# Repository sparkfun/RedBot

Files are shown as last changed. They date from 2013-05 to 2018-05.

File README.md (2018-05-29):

SparkFun RedBot
===============

<table class="table table-hover table-striped table-bordered">
  <tr align="center">
   <td><a href="https://www.sparkfun.com/products/12097">RedBot Mainboard</a></td>
   <td><a href="https://www.sparkfun.com/products/12649">RedBot Inventor's Kit for RedBot</a></td>
  </tr>
  <tr align="center">
    <td>RedBot Mainboard [<a href="https://www.sparkfun.com/products/12097">ROB-12097</a>]</td>
    <td>SparkFun Inventor's Kit for RedBot [<a href="https://www.sparkfun.com/products/12649">ROB-12649</a>]</td>
  </tr>
</table>

Design files and firmware files for the [RedBot Main board](https://www.sparkfun.com/products/11622).

Repository Contents
-------------------

* **/Documentation** - Documentation for the library's public API
* **/Hardware** - Eagle PCB layout files
* **/Libraries/Arduino/RedBot** - RedBot support library
* **/Production** - Files to support SparkFun production

Documentation
--------------

* **[Installing an Arduino Library Guide](https://learn.sparkfun.com/tutorials/installing-an-arduino-library)** - Basic information on how to install an Arduino library.
* **[Product Repository](https://github.com/sparkfun/RedBot)** - Main repository (including hardware files) for the RedBot.
* **[Library Repository](https://github.com/sparkfun/SparkFun_Redbot_Arduino_Library)** - Arduino library for the RedBot.
* **[Assembly Guide](https://learn.sparkfun.com/tutorials/assembly-guide-for-redbot-with-shadow-chassis)** - Basic hookup guide for the RedBot.
* **[Experiment Guide](https://learn.sparkfun.com/tutorials/experiment-guide-for-redbot-with-shadow-chassis)** - Experiment guide for the RedBot.

Product Versions
----------------
This repository only contains the hardware files for the RedBot Main board. There are several different support products available for the RedBot Kit however.

* [ROB-12097](https://www.sparkfun.com/products/12097) - RedBot Main Board.
* [ROB-12649](https://www.sparkfun.com/products/12649) - RedBot SparkFun Inventor's Kit
* *[ROB-13166 (RETIRED)](https://www.sparkfun.com/products/13166) - RedBot Basic Kit*
* [ROB-12567](https://www.sparkfun.com/products/12567) - RedBot Buzzer
* [SEN-11999](https://www.sparkfun.com/products/11999) - RedBot Mechanical Bumper
* [SEN-12589](https://www.sparkfun.com/products/12589) - RedBot Accelerometer
* [SEN-11769](https://www.sparkfun.com/products/11769) - RedBot Line Sensor
* [SEN-13582](https://www.sparkfun.com/products/13582) - SparkFun Line Follower Array

License Information
-------------------

This product is _**open source**_! 

Please review the LICENSE.md file for license information. 

If you have any questions or concerns on licensing, please contact techsupport@sparkfun.com.

Distributed as-is; no warranty is given.

- Your friends at SparkFun.

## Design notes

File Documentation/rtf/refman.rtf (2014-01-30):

begin body

TITLE

AUTHOR
Version
CREATEDATE

Table of Contents

Table of contents

Class Index
Class List
Here are the classes, structs, unions and interfaces with brief descriptions:
RedBotAccel pagenum
RedBotMotor pagenum
RedBotSensor pagenum

Class Documentation
RedBotAccel Class Reference
AAAAAAAAAAAAAAAAAAAA
#include <RedBot.h>

Public Member Functions
RedBotAccel ()
void read ()
void enableBump ()
boolean checkBump ()
void setBumpThresh (int xThresh)
Public Attributes
int x
int y
int z

Detailed Description
A class for controlling the RedBot's accelerometer.
Since the RedBot's accelerometer uses the I2C protocol, and is only connected to A4 and A5 on the RedBot, there should only ever be a single object of this class instantiated in your application/sketch.

Constructor & Destructor Documentation
RedBotAccel::RedBotAccel ()
AAAAAAAAABAAAAAAAAABCreates an object of the class RedBotAccel

Member Function Documentation
boolean RedBotAccel::checkBump ()
AAAAAAAAACAAAAAAAAACCheck to see if a "bump" event has occurred.
This method returns true if a "bump" event has occurred since the last time that RedBotAccel::checkBump() has been called. Before using RedBotAccel::checkBump(), bump detection must be enabled via RedBotAccel::enableBump(). Note that a "bump" is an acceleration event that occurs along the X-axis.
void RedBotAccel::enableBump ()
AAAAAAAAADAAAAAAAAADEnable bump detection.
A "bump" is an acceleration event that occurs along the X-axis. After enabling bump detection, use to RedBotAccel::checkBump() to do the actual detection.
void RedBotAccel::read ()
AAAAAAAAAEAAAAAAAAAECopy the current accelerometer values into the class's attributes.
In order to "read" the accelerometer's current state, you must first call RedBotAccel::read() to set RedBotAccel::x, RedBotAccel::y, and RedBotAccel::z which you can then read and do your own processing.
void RedBotAccel::setBumpThresh (int xThresh)
AAAAAAAAAFAAAAAAAAAFSet the threshold for what is considered a "bump" event.
If the default "bump" event threshold is too strong or too weak for your application/sketch, you can provide a value of 0-127 inclusive to use as the new threshold. Prior to calling RedBotAccel::setBumpThresh(int xTresh) "bump" detection must first be enabled via RedBotAccel::enableBump().

Member Data Documentation
int RedBotAccel::x
AAAAAAAAAGAAAAAAAAAGRead the last copied X-axis reading.
This class member is set by calling RedBotAccel::read() and can be used to do your own data processing.
int RedBotAccel::y
AAAAAAAAAHAAAAAAAAAHRead the last copied Y-axis reading.
This class member is set by calling RedBotAccel::read() and can be used to do your own data processing.
int RedBotAccel::z
AAAAAAAAAIAAAAAAAAAIRead the last copied Z-axis reading.
This class member is set by calling RedBotAccel::read() and can be used to do your own data processing.

The documentation for this class was generated from the following files:
Arduino/RedBot/RedBot.h
Arduino/RedBot/RedBotAccel.cpp

RedBotMotor Class Reference
AAAAAAAAAJAAAAAAAAAJ
#include <RedBot.h>

Public Member Functions
RedBotMotor ()
void drive (int speed)
void leftDrive (int speed)
void rightDrive (int speed)
void pivot (int speed)
void stop ()
void leftStop ()
void rightStop ()
void brake ()
void leftBrake ()
void rightBrake ()

Detailed Description
A class for controlling the RedBot's motors. A single object of the RedBotMotor class controls both the left and right motors of the RedBot.

Constructor & Destructor Documentation
RedBotMotor::RedBotMotor ()
AAAAAAAAAKAAAAAAAAAKCreate a new object of the RedBotMotor class.
A single RedBotMotor instance is used for both motors on the RedBot.

Member Function Documentation
void RedBotMotor::brake ()
AAAAAAAAALAAAAAAAAALImmediately stop both motors and hold their current positions.
The RedBotMotor::brake() method effectively shorts the terminals of the motors and therefore results in the motors stopping much more quickly than the RedBotMotor::stop() method. After a call to RedBotMotor::brake(), the motors will be much harder to turn, which will allow the RedBot to hold its position on a slope.
Usage Example:
#include <RedBot.h>

RedBotMotor motor;
void setup() {
}
void loop() {
// Drive for a bit
for (int x = 0; x < 1000; x++) {
motor.drive (200);
}
// Stop the motors and hold current position
motor.brake();
}
void RedBotMotor::drive (int speed)
AAAAAAAAAMAAAAAAAAAMRun both motors at a given speed.
If speed is a positive integer, drives both motors forward, and if speed is a negative integer, drives both motors backward. In either case, the motors are driven at the absolute value at speed . Allowable values for speed are -255 to 255 inclusive, however values in -75 to 0 and 0 to 75 inclusive may not provide enough torque to start the motor turning.
Usage Example:
#include <RedBot.h>

RedBotMotor motor;
void setup() {
}
void loop () {
// Drive forward at a speed of 200
motor.drive (200);
// Drive backward at a speed of 150
motor.drive (-150)
}
void RedBotMotor::leftBrake ()
AAAAAAAAANAAAAAAAAANImmediately stop the left motor and hold its current position.
The RedBotMotor::leftBrake() method effectively shorts the terminals of * the left motor and therefore results in the motor stopping much more quickly than the RedBotMotor::leftRtop() method. After a call to RedBotMotor::leftBrake(), the motor will be much harder to turn, which will allow the RedBot to hold its position on a slope. The right motor will still be able to be driven via RedBotMotor::rightDrive() method.
void RedBotMotor::leftDrive (int speed)
AAAAAAAAAOAAAAAAAAAORun the left motor at a given speed.
If speed is a positive integer, drives the motor forward, and if speed is a negative integer, drives motor backward. In either case, the motor is driven at the absolute value at speed . Allowable values for speed are -255 to 255 inclusive, however values in -75 to 0 and 0 to 75 inclusive may not provide enough torque to start the motor turning.
Usage Example:
#include <RedBot.h>

RedBotMotor motor;
void setup() {
}
void loop () {
// Drive the left motor forward at a speed of 200
motor.LeftDrive (200);
// Drive the left motor backward at a speed of 150
motor.leftDrive (-150)
}
void RedBotMotor::leftStop ()
AAAAAAAAAPAAAAAAAAAPDiscontinue PWM output to the left motor.
This method turns off the left motor by stopping PWM output to the motor. After a call to this method, the left motor will continue to coast for a short time. In order to continue driving just the right motor, use RedBotMotor::rightDrive(int speed)
void RedBotMotor::pivot (int speed)
AAAAAAAAAQAAAAAAAAAQPivot the RedBot to either the left or right.
If speed is a positive integer, the RedBot pivots to the left. If speed is a negative integer, the RedBot pivots to the right. In either case, the motors are driven in their respective directions at the absolute value of speed . When pivoting left, the left motor drives backwards and the right motor drives forward; when pivoting right, the motors drive in the opposite directions. Allowable values for speed are -255 to 255 inclusive, however values in -75 to 0 and 0 to 75 inclusive may not provide enough torque to start the motor turning.
Usage Example:
#include <RedBot.h>

RedBotMotor motor;
void setup() {
}
void loop() {
// Pivot to the left at a speed of 150
motor.pivot (150);
// Pivot to the right at a speed of 75
motor.pivot (-75);
}
void RedBotMotor::rightBrake ()
AAAAAAAAARAAAAAAAAARImmediately stop the right motor and hold its current position.
The RedBotMotor::rightBrake() method effectively shorts the terminals of the right motor and therefore results in the motor stopping much more quickly than the RedBotMotor::rightRtop() method. After a call to RedBotMotor::rightBrake(), the motor will be much harder to turn, which will allow the RedBot to hold its position on a slope. The left motor will still be able to be driven via RedBotMotor::leftDrive() method.
void RedBotMotor::rightDrive (int speed)
AAAAAAAAASAAAAAAAAASRun the right motor at a given speed.
If speed is a positive integer, drives the motor forward, and if speed is a negative integer, drives motor backward. In either case, the motor is driven at the absolute value at speed . Allowable values for speed are -255 to 255 inclusive, however values in -75 to 0 and 0 to 75 inclusive may not provide enough torque to start the motor turning.
Usage Example:
#include <RedBot.h>

RedBotMotor motor;
void setup() {
}
void loop () {
// Drive the right motor forward at a speed of 200
motor.RightDrive (200);
// Drive the right motor backward at a speed of 150
motor.rightDrive (-150)
}
void RedBotMotor::rightStop ()
AAAAAAAAATAAAAAAAAATDiscontinue PWM output to the right motor.
This method turns off the right motor by stopping PWM output to the motor. After a call to this method, the right motor will continue to coast for a short time. In order to continue driving just the left motor, use RedBotMotor::leftDrive(int speed)
void RedBotMotor::stop ()
AAAAAAAAAUAAAAAAAAAUDiscontinue PWM output to both motors.
This method turns off both motors by stopping PWM output to the motors. After a call to this method, the motors will continue to coast for a short time.
Usage Example:
#include <RedBot.h>

RedBotMotor motor;
void setup() {
}
void loop() {
// Drive for a bit
for (int x = 0; x < 1000; x++) {
motor.drive (200);
}
// Stop the motors
motor.stop();
}

The documentation for this class was generated from the following files:
Arduino/RedBot/RedBot.h
Arduino/RedBot/RedBotMotor.cpp

RedBotSensor Class Reference
AAAAAAAAAVAAAAAAAAAV
#include <RedBot.h>

Public Member Functions
RedBotSensor (int pin)
int read ()
boolean check ()
int setBGLevel ()
int setDetectLevel ()

Detailed Description
A class for controlling the RedBot's sensors.
A single object of the class RedBotSensor is needed for each sensor that you want to use on the RedBot.

Constructor & Destructor Documentation
RedBotSensor::RedBotSensor (int pin)
AAAAAAAAAWAAAAAAAAAWCreate a new object of the RedBotSensor class.
pin is the analog input pin that the sensor is connected to.
Usage Example:
#include <RedBot.h>

RedBotSensor sensor = RedBotSensor (A2);

Member Function Documentation
boolean RedBotSensor::check ()
AAAAAAAAAXAAAAAAAAAXDetermines if the current sensor reading is within the configured levels.
This method returns true if the sensor's current analog value is within the configured levels. If the sensor's current analog value is outside the configured levels, RedBotSensor::check() returns false .
int RedBotSensor::read ()
AAAAAAAAAYAAAAAAAAAYRead the analog level of the sensor.
This method is primarily used when you want to do your own data processing instead of relying on the library's edge detection.
int RedBotSensor::setBGLevel ()
AAAAAAAAAZAAAAAAAAAZSet the background/default sensor reading level.
Calling this method sets the sensor's reading level that corresponds to an uninteresting sensor reading. For example, if you are trying to follow a black line on a white background, you would call RedBotSensor::setBPLevel() when the light sensor is over the white background.
int RedBotSensor::setDetectLevel ()
AAAAAAAABAAAAAAAAABASet the forground/active sensor reading level.
Calling this method sets the sensor's reading level that corresponds to an interesting sensor reading. For example, if you are trying to follow a black line on a white background, you would call RedBotSensor::setDetectLevel() when the light sensor is over the black background.

The documentation for this class was generated from the following files:
Arduino/RedBot/RedBot.h
Arduino/RedBot/RedBotSensor.cpp

Index
INDEX

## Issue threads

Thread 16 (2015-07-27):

FTDI drivers and Codebender plugin not working to run from Browser

julesmoretti, 2015-07-27:
Hello there:

I have finished building the kit and am now at the following stage:
https://learn.sparkfun.com/tutorials/assembly-guide-for-redbot-with-shadow-chassis/10-run-it

I have a MacBook Pro retina and believe to have installed both the FTDI drivers and Codebender plugin.

At the very least the Codebender as it is listed in my chrome extensions as active.

The issue that I am facing is that within the "Test Some Code" section, I am unable to detect any other ports but:

```
/dev/cu.Bluetooth-Incoming-Port
/dev/cu.Bluetooth-Modem
```
So how can I troubleshoot this in order for me to be able to select COM42 as instructed in the tutorial?

Thank you for your help.

Jules

ToniCorinne, 2015-07-27:
Make sure you are powering the RedBot. If there's no power to the board, it won't show up in your available ports.

Double check you've completed these steps. If you aren't sure on these, reread the assembly guide and check out the images for additional help:
1) To program the RedBot from your browser, make sure you have the FTDI drivers and Codebender plugin) installed. Plug in the RedBot using a USB mini cable.
2) Turn the RedBot POWER switch to ON and the MOTOR switch to RUN.

ToniCorinne, 2015-07-27:
Also, your COM port will not necessarily be COM42. That number is assigned based on how many serial devices have been plugged in before. Check out our [terminal basics tutorial](https://learn.sparkfun.com/tutorials/terminal-basics/connecting-to-your-device) if you need additional help with this.

sean808080, 2015-11-13:
I'm having a similar problem in that the usbmodem port shows up.  The Arduino IDE works with it just fine.  The port when selected in the codebender test screen results in an error when attempting to load a test sketch:

Could not connect to your device. Make sure that you have connected it properly, that you have selected the correct settings (device type and port) and try again. More Info

Oh well....

tzikis, 2015-11-14:
hey @sean808080, can you please contact codebender's support at feedback.codebender.cc, in order to try and understand what's happening?

ToniCorinne, 2016-03-07:
We have updated this library and pushed the changes to both Codebender and the Arduino library manager. Please reopen this if you are still having issues.

Closed 2016-03-07.

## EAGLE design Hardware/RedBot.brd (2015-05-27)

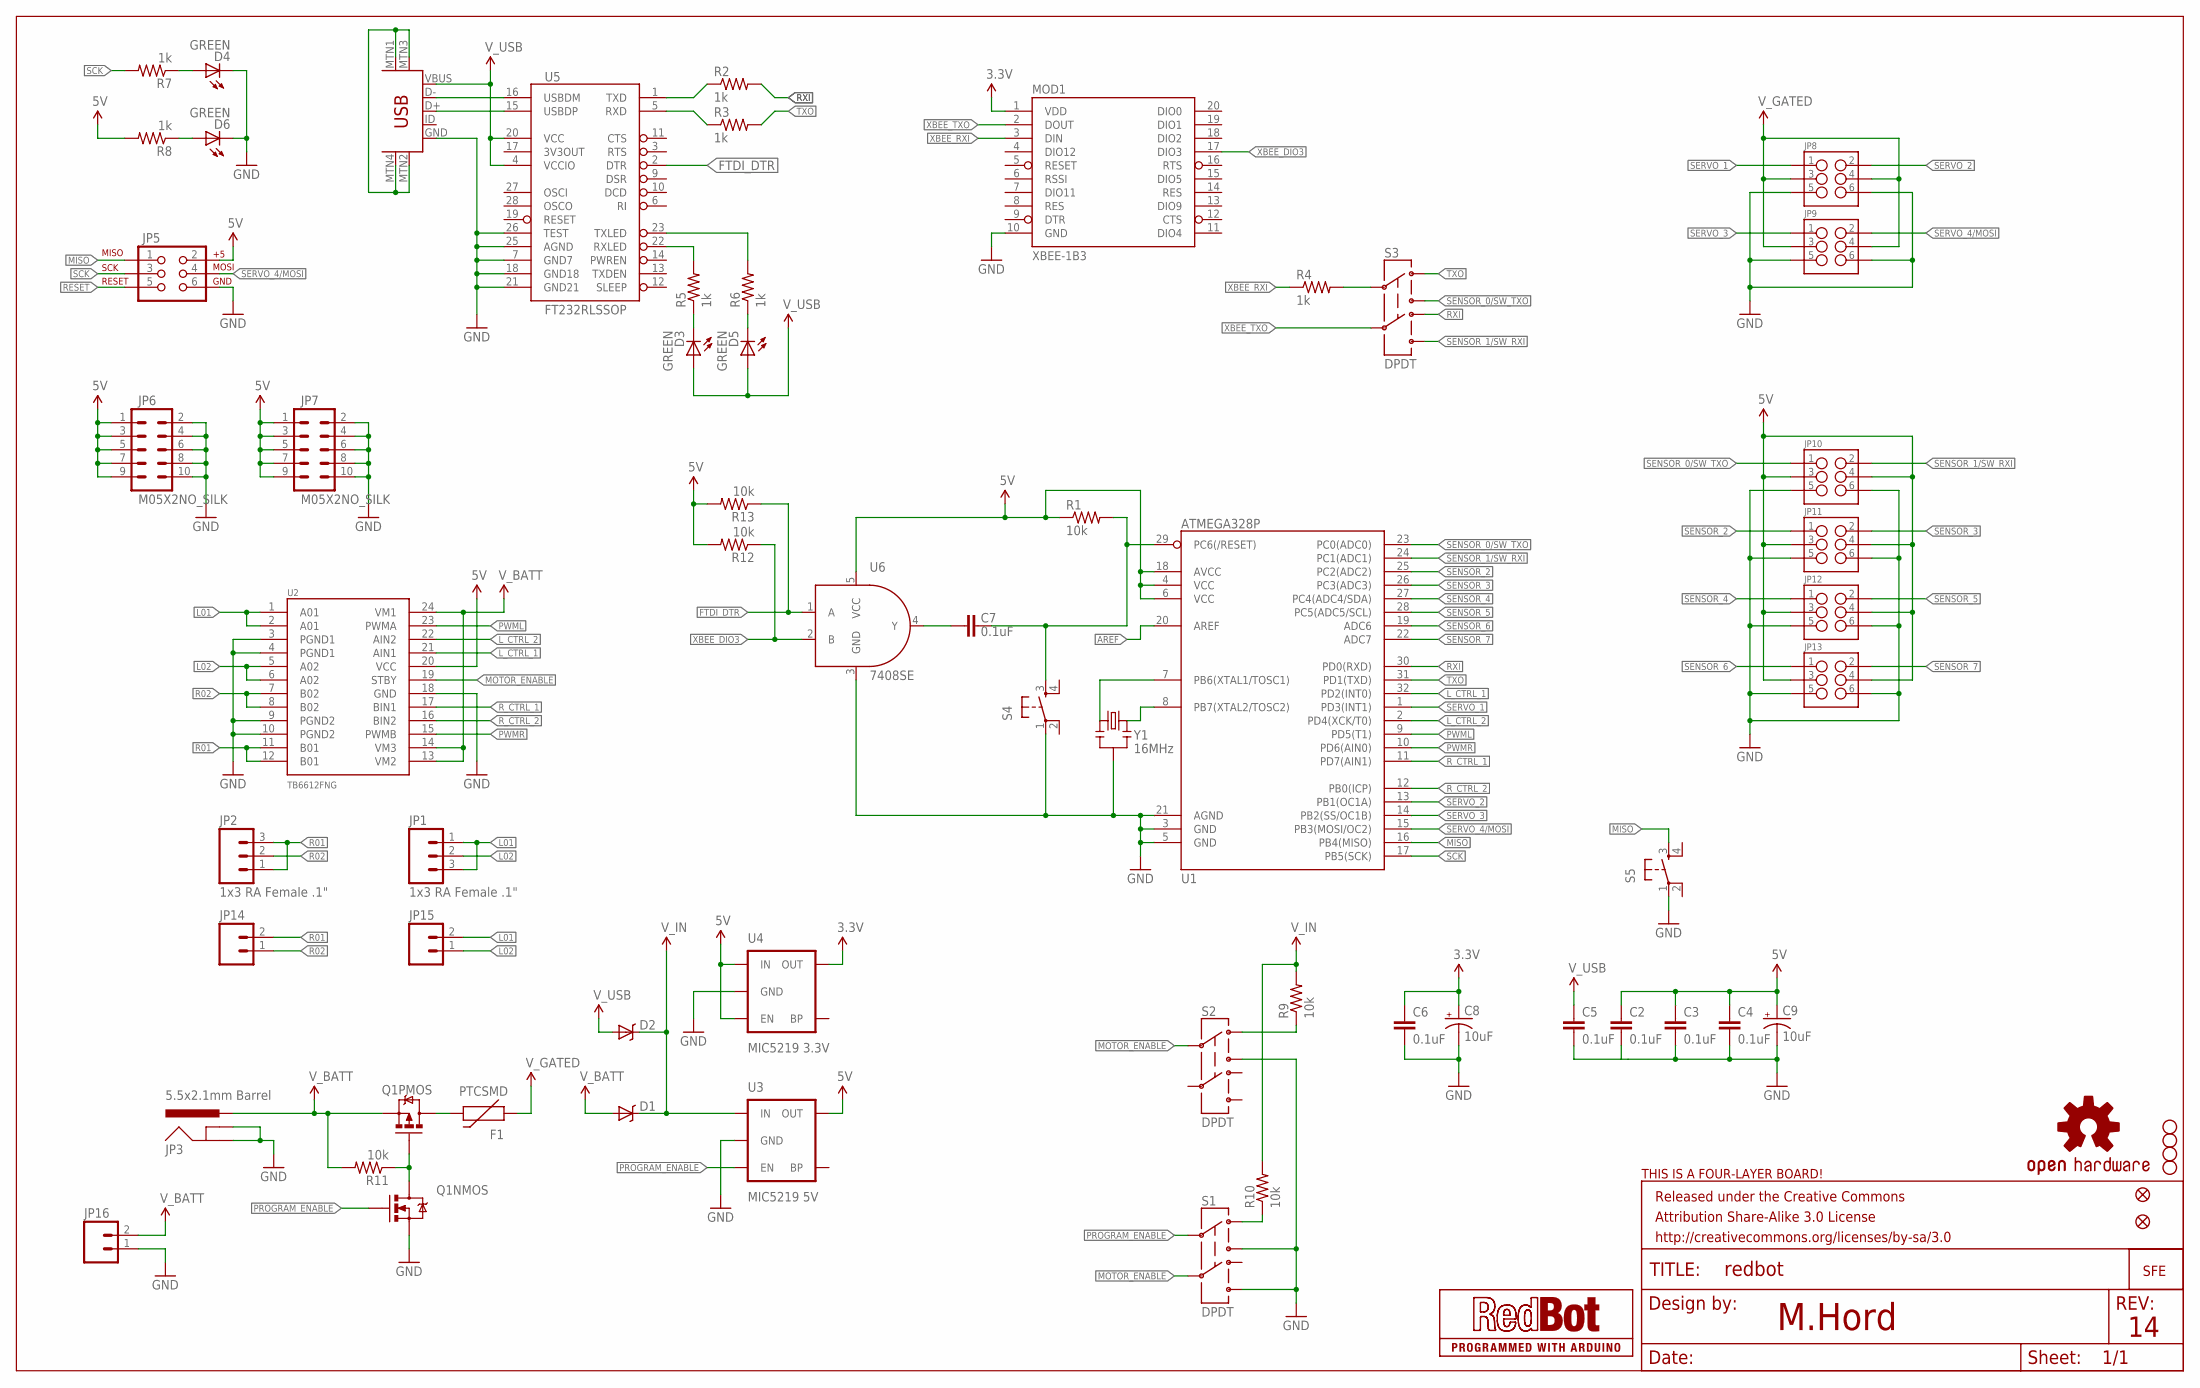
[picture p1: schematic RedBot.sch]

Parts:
C2, C3, C4, C5, C6, C7: 0.1uF; 0603-CAP
C8, C9: 10uF; EIA3216
D1, D2: B340A; SMA-DIODE
D3, D4, D5, D6: GREEN; LED-0603
F1: PTCSMD; PTC-1206
FID1, FID2: FIDUCIALUFIDUCIAL; MICRO-FIDUCIAL
FRAME1: FRAME-LETTER; CREATIVE_COMMONS
JP1, JP2: 1x3 RA Female .1"; 1X03_SMD_RA_FEMALE
JP3: 5.5x2.1mm Barrel; POWER_JACK_SMD
JP4: USB-B; USB-MINIB
JP5: AVR_SPI_PRG_6PTH; 2X3
JP6, JP7: M05X2NO_SILK; 2X5_NOSILK
JP8, JP9, JP10, JP11, JP12, JP13: M03X2SMT; 2X3_SMT_POSTS
JP14, JP15, JP16: M02PTH; 1X02
MOD1: XBEE-1B3; XBEE-SMD
Q1: IRF7509; MSOP8
R1, R9, R10, R11, R12, R13: 10k; 0603-RES
R2, R3, R4, R5, R6, R7, R8: 1k; 0603-RES
S1, S2, S3: DPDT; AYZ0202
S4, S5: TAC_SWITCHSMD; TACTILE_SWITCH_SMD
SFE-LOGO1: LOGO-SFENEW; SFE-NEW-WEBLOGO
STANDOFF1, STANDOFF2, STANDOFF3, STANDOFF4: STAND-OFF
U1: ATMEGA328P; TQFP32-08
U2: TB6612FNG; SSOP24
U3: MIC5219 5V; SOT23-5
U4: MIC5219 3.3V; SOT23-5
U5: FT232RLSSOP; SSOP28DB
U6: 7408SE; SOT353
U$17: OSHW-LOGOS; OSHW-LOGO-S
U$21: FOUR_LAYER_WARNING
U$23: REDBOT_LOGO
Y1: 16MHz; RESONATOR-SMD

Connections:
3.3V: C6.1, C8.A (+), MOD1.1 (VDD), U4.5 (OUT)
5V: C2.1, C3.1, C4.1, C9.A (+), JP5.2, JP6.1, JP6.3, JP6.5, JP6.7, JP6.9, JP7.1, JP7.3, JP7.5, JP7.7, JP7.9, JP10.3, JP10.4, JP11.3, JP11.4, JP12.3, JP12.4, JP13.3, JP13.4, R1.1, R8.2, R12.2, R13.2, U1.4 (VCC), U1.6 (VCC), U1.18 (AVCC), U2.20 (VCC), U3.5 (OUT), U4.1 (IN), U4.3 (EN), U6.5 (VCC)
AREF: U1.20 (AREF)
FT232_RXI: R3.1, U5.5 (RXD)
FT232_TXO: R2.1, U5.1 (TXD)
FTDI_DTR: R13.1, U5.2 (DTR), U6.1 (A)
GND: C2.2, C3.2, C4.2, C5.2, C6.2, C8.C (-), C9.C (-), D4.C, D6.C, JP3.GND (GNDBREAK), JP3.P$4 (GND), JP4.GND, JP5.6, JP6.2, JP6.4, JP6.6, JP6.8, JP6.10, JP7.2, JP7.4, JP7.6, JP7.8, JP7.10, JP8.5, JP8.6, JP9.5, JP9.6, JP10.5, JP10.6, JP11.5, JP11.6, JP12.5, JP12.6, JP13.5, JP13.6, JP16.1, MOD1.10 (GND), Q1.1 (S), S1.3, S1.6, S2.3, S4.1, S5.1, U1.3 (GND), U1.5 (GND), U1.21 (AGND), U2.3 (PGND1), U2.4 (PGND1), U2.9 (PGND2), U2.10 (PGND2), U2.18 (GND), U3.2 (GND), U4.2 (GND), U5.7 (GND7), U5.18 (GND18), U5.21 (GND21), U5.25 (AGND), U5.26 (TEST), U6.3 (GND), Y1.2
L01: JP1.1, JP1.3, JP15.2, U2.1 (A01), U2.2 (A01)
L02: JP1.2, JP15.1, U2.5 (A02), U2.6 (A02)
L_CTRL_1: U1.32 (PD2(INT0)), U2.21 (AIN1)
L_CTRL_2: U1.2 (PD4(XCK/T0)), U2.22 (AIN2)
MISO: JP5.1, S5.3, U1.16 (PB4(MISO))
MOTOR_ENABLE: S1.5, S2.2, U2.19 (STBY)
unnamed: R4.2, S3.2
unnamed: Q1.4 (G), Q1.7 (D), Q1.8 (D), R11.1
unnamed: D5.C, R6.1
unnamed: D3.C, R5.1
unnamed: C7.2, U6.4 (Y)
unnamed: JP4.MTN1 (MTN2), JP4.MTN2 (MTN3), JP4.MTN3 (MTN1), JP4.MTN4
unnamed: D4.A, R7.1
unnamed: D6.A, R8.1
unnamed: F1.2, Q1.5 (D), Q1.6 (D)
unnamed: R9.1, S2.1
unnamed: U1.8 (PB7(XTAL2/TOSC2)), Y1.3
unnamed: U1.7 (PB6(XTAL1/TOSC1)), Y1.1
unnamed: JP4.D-, U5.16 (USBDM)
unnamed: JP4.D+, U5.15 (USBDP)
PG_EN: R10.1, S1.1
PROGRAM_ENABLE: Q1.2 (G), S1.2, U3.3 (EN)
PWML: U1.9 (PD5(T1)), U2.23 (PWMA)
PWMR: U1.10 (PD6(AIN0)), U2.15 (PWMB)
R01: JP2.1, JP2.3, JP14.2, U2.11 (B01), U2.12 (B01)
R02: JP2.2, JP14.1, U2.7 (B02), U2.8 (B02)
RESET: C7.1, JP5.5, R1.2, S4.3, U1.29 (PC6(/RESET))
RXI: R2.2, S3.4, U1.30 (PD0(RXD))
RXLED: R5.2, U5.22 (RXLED)
R_CTRL_1: U1.11 (PD7(AIN1)), U2.17 (BIN1)
R_CTRL_2: U1.12 (PB0(ICP)), U2.16 (BIN2)
SCK: JP5.3, R7.2, U1.17 (PB5(SCK))
SENSOR_0/SW_TXO: JP10.1, S3.3, U1.23 (PC0(ADC0))
SENSOR_1/SW_RXI: JP10.2, S3.6, U1.24 (PC1(ADC1))
SENSOR_2: JP11.1, U1.25 (PC2(ADC2))
SENSOR_3: JP11.2, U1.26 (PC3(ADC3))
SENSOR_4: JP12.1, U1.27 (PC4(ADC4/SDA))
SENSOR_5: JP12.2, U1.28 (PC5(ADC5/SCL))
SENSOR_6: JP13.1, U1.19 (ADC6)
SENSOR_7: JP13.2, U1.22 (ADC7)
SERVO_1: JP8.1, U1.1 (PD3(INT1))
SERVO_2: JP8.2, U1.13 (PB1(OC1A))
SERVO_3: JP9.1, U1.14 (PB2(SS/OC1B))
SERVO_4/MOSI: JP5.4, JP9.2, U1.15 (PB3(MOSI/OC2))
TXLED: R6.2, U5.23 (TXLED)
TXO: R3.2, S3.1, U1.31 (PD1(TXD))
V_BATT: D1.A, JP3.VIN0 (PWR), JP16.2, Q1.3 (S), R11.2, U2.13 (VM2), U2.14 (VM3), U2.24 (VM1)
V_GATED: F1.1, JP8.3, JP8.4, JP9.3, JP9.4
V_IN: D1.C, D2.C, R9.2, R10.2, U3.1 (IN)
V_USB: C5.1, D2.A, D3.A, D5.A, JP4.VBUS, U5.4 (VCCIO), U5.20 (VCC)
XBEE_DIO3: MOD1.17 (DIO3), R12.1, U6.2 (B)
XBEE_RXI: MOD1.3 (DIN), R4.1
XBEE_TXO: MOD1.2 (DOUT), S3.5

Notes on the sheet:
M.Hord

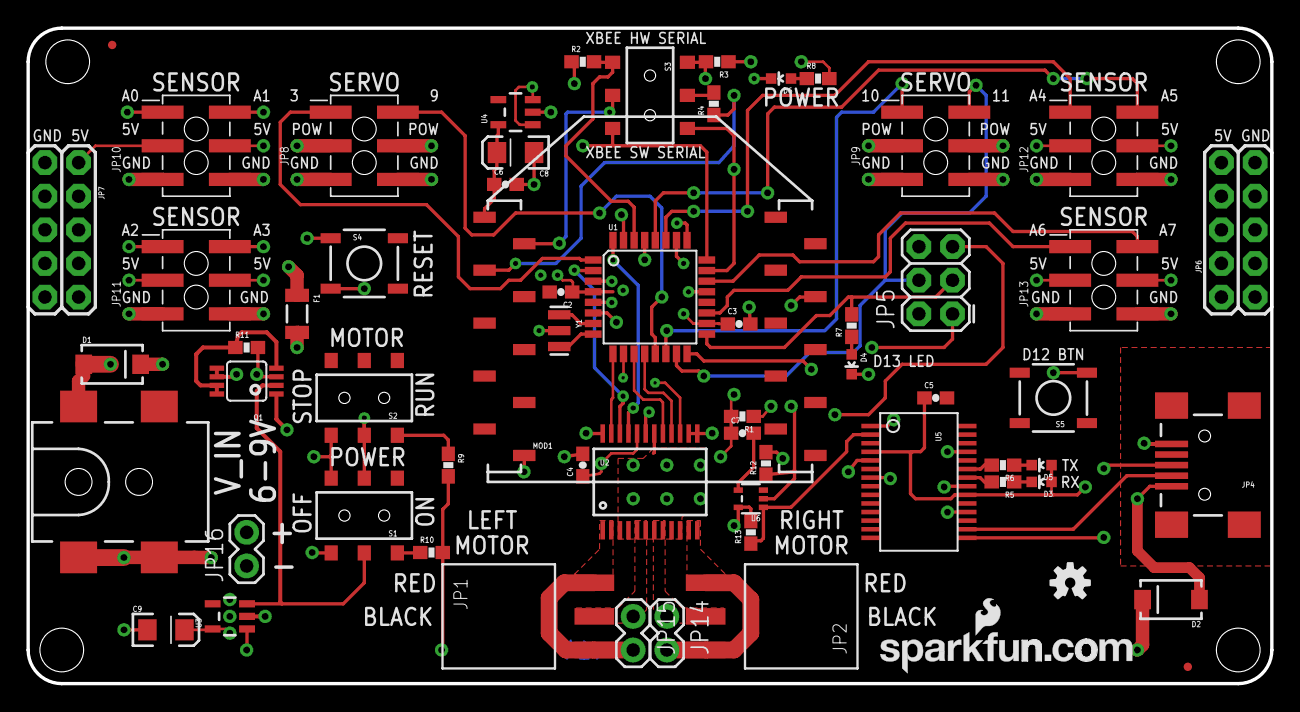
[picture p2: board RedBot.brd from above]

Board: 4 copper layers, 94.0 x 49.5 mm, 69 parts (1 on the bottom side), 59 nets.

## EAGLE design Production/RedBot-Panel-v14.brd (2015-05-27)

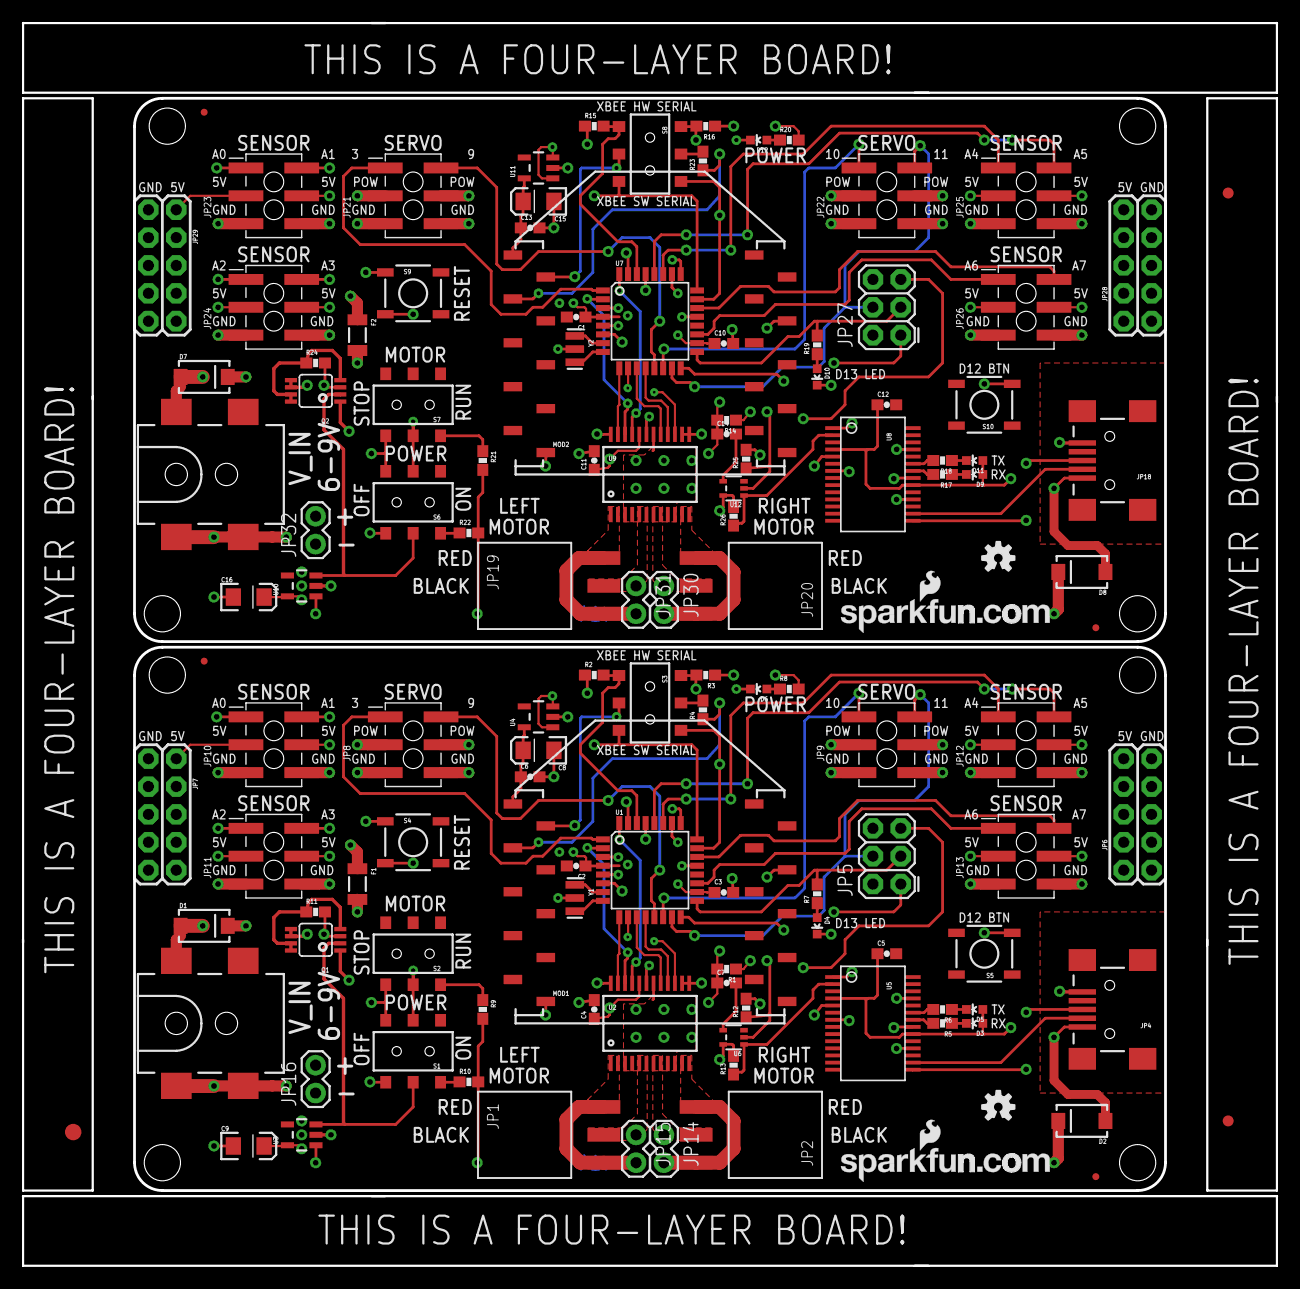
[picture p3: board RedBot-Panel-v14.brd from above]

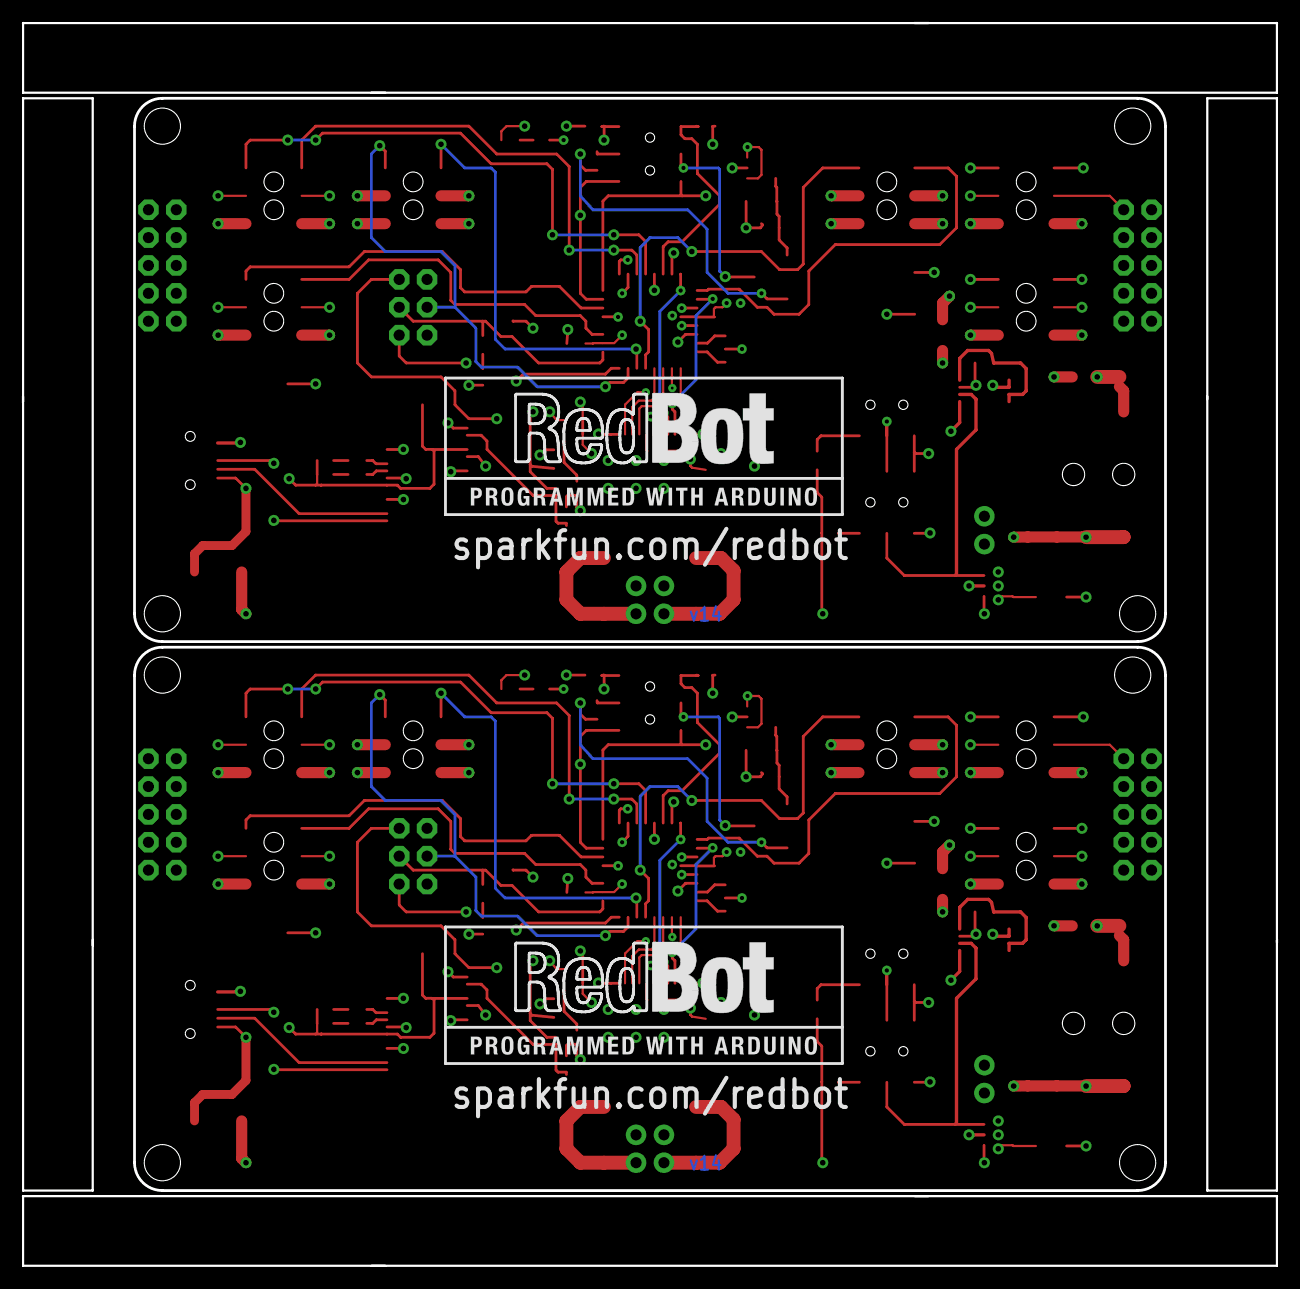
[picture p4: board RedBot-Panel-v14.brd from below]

Board: 4 copper layers, 114.3 x 113.3 mm, 137 parts (2 on the bottom side), 118 nets.

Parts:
C1, C2, C3, C4, C5, C6, C7, C10, C11, C12, C13, C14: 0.1uF; 0603-CAP
C8, C9, C15, C16: 10uF; EIA3216
D1, D2, D7, D8: SMA-DIODE
D3, D4, D5, D6, D9, D10, D11, D12: GREEN; LED-0603
E$1: FIDUCIAL-1.5X3
E$2, E$6: FIDUCIAL-1X2
F1, F2: PTCSMD; PTC-1206
FID1, FID2, FID3, FID4: FIDUCIALUFIDUCIAL; MICRO-FIDUCIAL
JP1, JP2, JP19, JP20: 1x3 RA Female .1"; 1X03_SMD_RA_FEMALE
JP3, JP17: 5.5x2.1mm Barrel; POWER_JACK_SMD
JP4, JP18: USB-B; USB-MINIB
JP5, JP27: AVR_SPI_PRG_6PTH; 2X3
JP6, JP7, JP28, JP29: M05X2NO_SILK; 2X5_NOSILK
JP8, JP9, JP10, JP11, JP12, JP13, JP21, JP22, JP23, JP24, JP25, JP26: 2X3_SMT_POSTS
JP14, JP15, JP16, JP30, JP31, JP32: 1X02
MOD1, MOD2: XBEE-1B3; XBEE-SMD
Q1, Q2: MSOP8
R1, R9, R10, R11, R12, R13, R14, R21, R22, R24, R25, R26: 10k; 0603-RES
R2, R3, R4, R5, R6, R7, R8, R15, R16, R17, R18, R19, R20, R23: 1k; 0603-RES
S1, S2, S3, S6, S7, S8: DPDT; AYZ0202
S4, S5, S9, S10: TACTILE_SWITCH_SMD
SFE-LOGO1, SFE-LOGO2: LOGO-SFENEW; SFE-NEW-WEBLOGO
STANDOFF1, STANDOFF2, STANDOFF3, STANDOFF4, STANDOFF5, STANDOFF6, STANDOFF7, STANDOFF8: STAND-OFF
U1, U7: ATMEGA328P; TQFP32-08
U2, U9: TB6612FNG; SSOP24
U3, U10: MIC5219 5V; SOT23-5
U4, U11: MIC5219 3.3V; SOT23-5
U5, U8: FT232RLSSOP; SSOP28DB
U6, U12: 7408SE; SOT353
U$1, U$17: OSHW-LOGOS; OSHW-LOGO-S
U$2, U$23: REDBOT_LOGO
Y1, Y2: 16MHz; RESONATOR-SMD

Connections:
3.3V: C6.1, C8.A, MOD1.1, U4.5
3.3V1: C13.1, C15.A, MOD2.1, U11.5
5V: C2.1, C3.1, C4.1, C9.A, JP5.2, JP6.1, JP6.3, JP6.5, JP6.7, JP6.9, JP7.1, JP7.3, JP7.5, JP7.7, JP7.9, JP10.3, JP10.4, JP11.3, JP11.4, JP12.3, JP12.4, JP13.3, JP13.4, R1.1, R8.2, R12.2, R13.2, U1.4, U1.6, U1.18, U2.20, U3.5, U4.1, U4.3, U6.5
5V1: C1.1, C10.1, C11.1, C16.A, JP23.3, JP23.4, JP24.3, JP24.4, JP25.3, JP25.4, JP26.3, JP26.4, JP27.2, JP28.1, JP28.3, JP28.5, JP28.7, JP28.9, JP29.1, JP29.3, JP29.5, JP29.7, JP29.9, R14.1, R20.2, R25.2, R26.2, U7.4, U7.6, U7.18, U9.20, U10.5, U11.1, U11.3, U12.5
FT232_RXI: R3.1, U5.5
FT232_RXI1: R16.1, U8.5
FT232_TXO: R2.1, U5.1
FT232_TXO1: R15.1, U8.1
FTDI_DTR: R13.1, U5.2, U6.1
FTDI_DTR1: R26.1, U8.2, U12.1
GND: C2.2, C3.2, C4.2, C5.2, C6.2, C8.C, C9.C, D4.C, D6.C, JP3.GND, JP3.P$4, JP4.GND, JP5.6, JP6.2, JP6.4, JP6.6, JP6.8, JP6.10, JP7.2, JP7.4, JP7.6, JP7.8, JP7.10, JP8.5, JP8.6, JP9.5, JP9.6, JP10.5, JP10.6, JP11.5, JP11.6, JP12.5, JP12.6, JP13.5, JP13.6, JP16.1, MOD1.10, Q1.1, S1.3, S1.6, S2.3, S4.1, S5.1, U1.3, U1.5, U1.21, U2.3, U2.4, U2.9, U2.10, U2.18, U3.2, U4.2, U5.7, U5.18, U5.21, U5.25, U5.26, U6.3, Y1.2
GND1: C1.2, C10.2, C11.2, C12.2, C13.2, C15.C, C16.C, D10.C, D12.C, JP17.GND, JP17.P$4, JP18.GND, JP21.5, JP21.6, JP22.5, JP22.6, JP23.5, JP23.6, JP24.5, JP24.6, JP25.5, JP25.6, JP26.5, JP26.6, JP27.6, JP28.2, JP28.4, JP28.6, JP28.8, JP28.10, JP29.2, JP29.4, JP29.6, JP29.8, JP29.10, JP32.1, MOD2.10, Q2.1, S6.3, S6.6, S7.3, S9.1, S10.1, U7.3, U7.5, U7.21, U8.7, U8.18, U8.21, U8.25, U8.26, U9.3, U9.4, U9.9, U9.10, U9.18, U10.2, U11.2, U12.3, Y2.2
L01: JP1.1, JP1.3, JP15.2, U2.1, U2.2
L02: JP1.2, JP15.1, U2.5, U2.6
L03: JP19.1, JP19.3, JP31.2, U9.1, U9.2
L04: JP19.2, JP31.1, U9.5, U9.6
L_CTRL_1: U1.32, U2.21
L_CTRL_2: U1.2, U2.22
L_CTRL_3: U7.2, U9.22
L_CTRL_4: U7.32, U9.21
MISO: JP5.1, S5.3, U1.16
MISO1: JP27.1, S10.3, U7.16
MOTOR_ENABLE: S1.5, S2.2, U2.19
MOTOR_ENABLE1: S6.5, S7.2, U9.19
unnamed: R4.2, S3.2
unnamed: Q1.4, Q1.7, Q1.8, R11.1
unnamed: D5.C, R6.1
unnamed: D3.C, R5.1
unnamed: C7.2, U6.4
unnamed: JP4.MTN1, JP4.MTN2, JP4.MTN3, JP4.MTN4
unnamed: D4.A, R7.1
unnamed: D6.A, R8.1
unnamed: F1.2, Q1.5, Q1.6
unnamed: JP18.D-, U8.16
unnamed: JP18.D+, U8.15
unnamed: U7.8, Y2.3
unnamed: U7.7, Y2.1
unnamed: D10.A, R19.1
unnamed: D12.A, R20.1
unnamed: R21.1, S7.1
unnamed: C14.2, U12.4
unnamed: R9.1, S2.1
unnamed: R23.2, S8.2
unnamed: JP18.MTN1, JP18.MTN2, JP18.MTN3, JP18.MTN4
unnamed: Q2.4, Q2.7, Q2.8, R24.1
unnamed: D11.C, R18.1
unnamed: U1.8, Y1.3
unnamed: U1.7, Y1.1
unnamed: D9.C, R17.1
unnamed: JP4.D-, U5.16
unnamed: JP4.D+, U5.15
unnamed: F2.2, Q2.5, Q2.6
PG_EN: R10.1, S1.1
PG_EN1: R22.1, S6.1
PROGRAM_ENABLE: Q1.2, S1.2, U3.3
PROGRAM_ENABLE1: Q2.2, S6.2, U10.3
PWML: U1.9, U2.23
PWML1: U7.9, U9.23
PWMR: U1.10, U2.15
PWMR1: U7.10, U9.15
R01: JP2.1, JP2.3, JP14.2, U2.11, U2.12
R02: JP2.2, JP14.1, U2.7, U2.8
R03: JP20.2, JP30.1, U9.7, U9.8
R04: JP20.1, JP20.3, JP30.2, U9.11, U9.12
RESET: C7.1, JP5.5, R1.2, S4.3, U1.29
RESET1: C14.1, JP27.5, R14.2, S9.3, U7.29
RXI: R2.2, S3.4, U1.30
RXI1: R15.2, S8.4, U7.30
RXLED: R5.2, U5.22
RXLED1: R17.2, U8.22
R_CTRL_1: U1.11, U2.17
R_CTRL_2: U1.12, U2.16
R_CTRL_3: U7.11, U9.17
R_CTRL_4: U7.12, U9.16
SCK: JP5.3, R7.2, U1.17
SCK1: JP27.3, R19.2, U7.17
SENSOR_0/SW_TXO: JP10.1, S3.3, U1.23
SENSOR_0/SW_TXO1: JP23.1, S8.3, U7.23
SENSOR_1: JP24.1, U7.25
SENSOR_1/SW_RXI: JP10.2, S3.6, U1.24
SENSOR_1/SW_RXI1: JP23.2, S8.6, U7.24
SENSOR_2: JP11.1, U1.25
SENSOR_3: JP11.2, U1.26
SENSOR_4: JP12.1, U1.27
SENSOR_5: JP12.2, U1.28
SENSOR_6: JP13.1, U1.19
SENSOR_7: JP13.2, U1.22
SENSOR_8: JP24.2, U7.26
SENSOR_9: JP25.1, U7.27
SENSOR_10: JP25.2, U7.28
SENSOR_11: JP26.1, U7.19
SENSOR_12: JP26.2, U7.22
SERVO_1: JP8.1, U1.1
SERVO_2: JP8.2, U1.13
SERVO_3: JP9.1, U1.14
SERVO_4: JP21.1, U7.1
SERVO_4/MOSI: JP5.4, JP9.2, U1.15
SERVO_4/MOSI1: JP22.2, JP27.4, U7.15
SERVO_5: JP21.2, U7.13
SERVO_6: JP22.1, U7.14
TXLED: R6.2, U5.23
TXLED1: R18.2, U8.23
TXO: R3.2, S3.1, U1.31
TXO1: R16.2, S8.1, U7.31
V_BATT: D1.A, JP3.VIN0, JP16.2, Q1.3, R11.2, U2.13, U2.14, U2.24
V_BATT1: D7.A, JP17.VIN0, JP32.2, Q2.3, R24.2, U9.13, U9.14, U9.24
V_GATED: F1.1, JP8.3, JP8.4, JP9.3, JP9.4
V_GATED1: F2.1, JP21.3, JP21.4, JP22.3, JP22.4
V_IN: D1.C, D2.C, R9.2, R10.2, U3.1
V_IN1: D7.C, D8.C, R21.2, R22.2, U10.1
V_USB: C5.1, D2.A, D3.A, D5.A, JP4.VBUS, U5.4, U5.20
V_USB1: C12.1, D8.A, D9.A, D11.A, JP18.VBUS, U8.4, U8.20
XBEE_DIO1: MOD2.17, R25.1, U12.2
XBEE_DIO3: MOD1.17, R12.1, U6.2
XBEE_RXI: MOD1.3, R4.1
XBEE_RXI1: MOD2.3, R23.1
XBEE_TXO: MOD1.2, S3.5
XBEE_TXO1: MOD2.2, S8.5

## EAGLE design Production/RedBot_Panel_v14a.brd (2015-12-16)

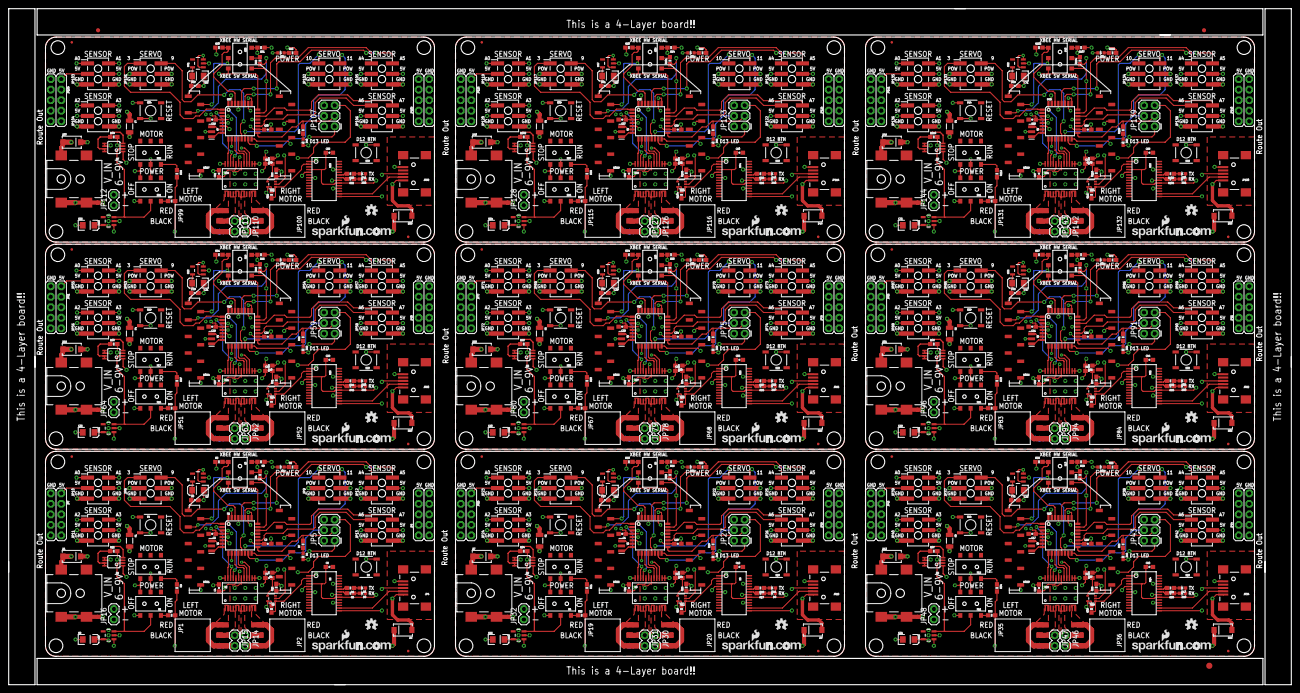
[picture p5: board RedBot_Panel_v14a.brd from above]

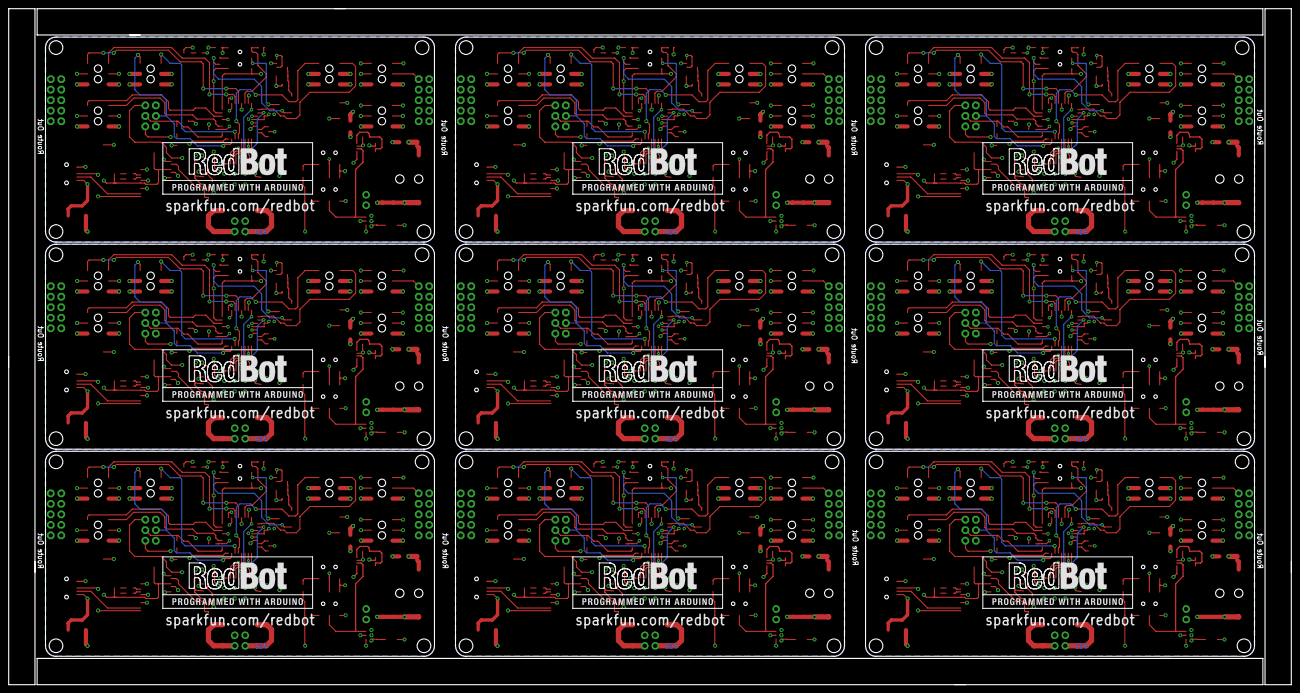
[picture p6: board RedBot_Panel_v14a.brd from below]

Board: 4 copper layers, 309.9 x 163.3 mm, 606 parts (9 on the bottom side), 531 nets.

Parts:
C1, C2, C3, C4, C5, C6, C7, C10, C11, C12, C13, C14, C17, C18, C19, C20, C21, C22, C25, C26, C27, C28, C29, C30, C33, C34, C35, C36, C37, C38, C41, C42, C43, C44, C45, C46, C49, C50, C51, C52, C53, C54, C57, C58, C59, C60, C61, C62, C65, C66, C67, C68, C69, C70: 0.1uF; 0603-CAP
C8, C9, C15, C16, C23, C24, C31, C32, C39, C40, C47, C48, C55, C56, C63, C64, C71, C72: 10uF; EIA3216
D1, D2, D7, D8, D13, D14, D19, D20, D25, D26, D31, D32, D37, D38, D43, D44, D49, D50: SMA-DIODE
D3, D4, D5, D6, D9, D10, D11, D12, D15, D16, D17, D18, D21, D22, D23, D24, D27, D28, D29, D30, D33, D34, D35, D36, D39, D40, D41, D42, D45, D46, D47, D48, D51, D52, D53, D54: GREEN; LED-0603
E$1: FIDUCIAL-1.5X3
E$7, E$8: FIDUCIAL-1X2
F1, F2, F3, F4, F5, F6, F7, F8, F9: PTCSMD; PTC-1206
FID1, FID2, FID3, FID4, FID5, FID6, FID7, FID8, FID9, FID10, FID11, FID12, FID13, FID14, FID15, FID16, FID17, FID18: FIDUCIALUFIDUCIAL; MICRO-FIDUCIAL
JP1, JP2, JP19, JP20, JP35, JP36, JP51, JP52, JP67, JP68, JP83, JP84, JP99, JP100, JP115, JP116, JP131, JP132: 1x3 RA Female .1"; 1X03_SMD_RA_FEMALE
JP3, JP17, JP33, JP49, JP65, JP81, JP97, JP113, JP129: 5.5x2.1mm Barrel; POWER_JACK_SMD
JP4, JP18, JP34, JP50, JP66, JP82, JP98, JP114, JP130: USB-B; USB-MINIB
JP5, JP27, JP43, JP59, JP75, JP91, JP107, JP123, JP139: AVR_SPI_PRG_6PTH; 2X3
JP6, JP7, JP28, JP29, JP44, JP45, JP60, JP61, JP76, JP77, JP92, JP93, JP108, JP109, JP124, JP125, JP140, JP141: M05X2NO_SILK; 2X5_NOSILK
JP8, JP9, JP10, JP11, JP12, JP13, JP21, JP22, JP23, JP24, JP25, JP26, JP37, JP38, JP39, JP40, JP41, JP42, JP53, JP54, JP55, JP56, JP57, JP58, JP69, JP70, JP71, JP72, JP73, JP74, JP85, JP86, JP87, JP88, JP89, JP90, JP101, JP102, JP103, JP104, JP105, JP106, JP117, JP118, JP119, JP120, JP121, JP122, JP133, JP134, JP135, JP136, JP137, JP138: 2X3_SMT_POSTS
JP14, JP15, JP16, JP30, JP31, JP32, JP46, JP47, JP48, JP62, JP63, JP64, JP78, JP79, JP80, JP94, JP95, JP96, JP110, JP111, JP112, JP126, JP127, JP128, JP142, JP143, JP144: 1X02
MOD1, MOD2, MOD3, MOD4, MOD5, MOD6, MOD7, MOD8, MOD9: XBEE-1B3; XBEE-SMD
Q1, Q2, Q3, Q4, Q5, Q6, Q7, Q8, Q9: MSOP8
R1, R9, R10, R11, R12, R13, R14, R21, R22, R24, R25, R26, R27, R34, R35, R37, R38, R39, R40, R47, R48, R50, R51, R52, R53, R60, R61, R63, R64, R65, R66, R73, R74, R76, R77, R78, R79, R86, R87, R89, R90, R91, R92, R99, R100, R102, R103, R104, R105, R112, R113, R115, R116, R117: 10k; 0603-RES
R2, R3, R4, R5, R6, R7, R8, R15, R16, R17, R18, R19, R20, R23, R28, R29, R30, R31, R32, R33, R36, R41, R42, R43, R44, R45, R46, R49, R54, R55, R56, R57, R58, R59, R62, R67, R68, R69, R70, R71, R72, R75, R80, R81, R82, R83, R84, R85, R88, R93, R94, R95, R96, R97, R98, R101, R106, R107, R108, R109, R110, R111, R114: 1k; 0603-RES
S1, S2, S3, S6, S7, S8, S11, S12, S13, S16, S17, S18, S21, S22, S23, S26, S27, S28, S31, S32, S33, S36, S37, S38, S41, S42, S43: DPDT; AYZ0202
S4, S5, S9, S10, S14, S15, S19, S20, S24, S25, S29, S30, S34, S35, S39, S40, S44, S45: TACTILE_SWITCH_SMD
SFE-LOGO1, SFE-LOGO2, SFE-LOGO3, SFE-LOGO4, SFE-LOGO5, SFE-LOGO6, SFE-LOGO7, SFE-LOGO8, SFE-LOGO9: LOGO-SFENEW; SFE-NEW-WEBLOGO
STANDOFF1, STANDOFF2, STANDOFF3, STANDOFF4, STANDOFF5, STANDOFF6, STANDOFF7, STANDOFF8, STANDOFF9, STANDOFF10, STANDOFF11, STANDOFF12, STANDOFF13, STANDOFF14, STANDOFF15, STANDOFF16, STANDOFF17, STANDOFF18, STANDOFF19, STANDOFF20, STANDOFF21, STANDOFF22, STANDOFF23, STANDOFF24, STANDOFF25, STANDOFF26, STANDOFF27, STANDOFF28, STANDOFF29, STANDOFF30, STANDOFF31, STANDOFF32, STANDOFF33, STANDOFF34, STANDOFF35, STANDOFF36: STAND-OFF
U1, U7, U13, U19, U25, U31, U37, U43, U49: ATMEGA328P; TQFP32-08
U2, U9, U15, U21, U27, U33, U39, U45, U51: TB6612FNG; SSOP24
U3, U10, U16, U22, U28, U34, U40, U46, U52: MIC5219 5V; SOT23-5
U4, U11, U17, U23, U29, U35, U41, U47, U53: MIC5219 3.3V; SOT23-5
U5, U8, U14, U20, U26, U32, U38, U44, U50: FT232RLSSOP; SSOP28DB
U6, U12, U18, U24, U30, U36, U42, U48, U54: 7408SE; SOT353
U$1, U$3, U$5, U$7, U$9, U$11, U$13, U$15, U$17: OSHW-LOGOS; OSHW-LOGO-S
U$2, U$4, U$6, U$8, U$10, U$12, U$14, U$16, U$23: REDBOT_LOGO
Y1, Y2, Y3, Y4, Y5, Y6, Y7, Y8, Y9: 16MHz; RESONATOR-SMD

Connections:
3.3V: C6.1, C8.A, MOD1.1, U4.5
3.3V1: C13.1, C15.A, MOD2.1, U11.5
3.3V2: C21.1, C23.A, MOD3.1, U17.5
3.3V3: C29.1, C31.A, MOD4.1, U23.5
3.3V4: C37.1, C39.A, MOD5.1, U29.5
3.3V5: C45.1, C47.A, MOD6.1, U35.5
3.3V6: C53.1, C55.A, MOD7.1, U41.5
3.3V7: C61.1, C63.A, MOD8.1, U47.5
3.3V8: C69.1, C71.A, MOD9.1, U53.5
5V: C2.1, C3.1, C4.1, C9.A, JP5.2, JP6.1, JP6.3, JP6.5, JP6.7, JP6.9, JP7.1, JP7.3, JP7.5, JP7.7, JP7.9, JP10.3, JP10.4, JP11.3, JP11.4, JP12.3, JP12.4, JP13.3, JP13.4, R1.1, R8.2, R12.2, R13.2, U1.4, U1.6, U1.18, U2.20, U3.5, U4.1, U4.3, U6.5
5V1: C1.1, C10.1, C11.1, C16.A, JP23.3, JP23.4, JP24.3, JP24.4, JP25.3, JP25.4, JP26.3, JP26.4, JP27.2, JP28.1, JP28.3, JP28.5, JP28.7, JP28.9, JP29.1, JP29.3, JP29.5, JP29.7, JP29.9, R14.1, R20.2, R25.2, R26.2, U7.4, U7.6, U7.18, U9.20, U10.5, U11.1, U11.3, U12.5
5V2: C17.1, C18.1, C19.1, C24.A, JP39.3, JP39.4, JP40.3, JP40.4, JP41.3, JP41.4, JP42.3, JP42.4, JP43.2, JP44.1, JP44.3, JP44.5, JP44.7, JP44.9, JP45.1, JP45.3, JP45.5, JP45.7, JP45.9, R27.1, R33.2, R38.2, R39.2, U13.4, U13.6, U13.18, U15.20, U16.5, U17.1, U17.3, U18.5
5V3: C25.1, C26.1, C27.1, C32.A, JP55.3, JP55.4, JP56.3, JP56.4, JP57.3, JP57.4, JP58.3, JP58.4, JP59.2, JP60.1, JP60.3, JP60.5, JP60.7, JP60.9, JP61.1, JP61.3, JP61.5, JP61.7, JP61.9, R40.1, R46.2, R51.2, R52.2, U19.4, U19.6, U19.18, U21.20, U22.5, U23.1, U23.3, U24.5
5V4: C33.1, C34.1, C35.1, C40.A, JP71.3, JP71.4, JP72.3, JP72.4, JP73.3, JP73.4, JP74.3, JP74.4, JP75.2, JP76.1, JP76.3, JP76.5, JP76.7, JP76.9, JP77.1, JP77.3, JP77.5, JP77.7, JP77.9, R53.1, R59.2, R64.2, R65.2, U25.4, U25.6, U25.18, U27.20, U28.5, U29.1, U29.3, U30.5
5V5: C41.1, C42.1, C43.1, C48.A, JP87.3, JP87.4, JP88.3, JP88.4, JP89.3, JP89.4, JP90.3, JP90.4, JP91.2, JP92.1, JP92.3, JP92.5, JP92.7, JP92.9, JP93.1, JP93.3, JP93.5, JP93.7, JP93.9, R66.1, R72.2, R77.2, R78.2, U31.4, U31.6, U31.18, U33.20, U34.5, U35.1, U35.3, U36.5
5V6: C49.1, C50.1, C51.1, C56.A, JP103.3, JP103.4, JP104.3, JP104.4, JP105.3, JP105.4, JP106.3, JP106.4, JP107.2, JP108.1, JP108.3, JP108.5, JP108.7, JP108.9, JP109.1, JP109.3, JP109.5, JP109.7, JP109.9, R79.1, R85.2, R90.2, R91.2, U37.4, U37.6, U37.18, U39.20, U40.5, U41.1, U41.3, U42.5
5V7: C57.1, C58.1, C59.1, C64.A, JP119.3, JP119.4, JP120.3, JP120.4, JP121.3, JP121.4, JP122.3, JP122.4, JP123.2, JP124.1, JP124.3, JP124.5, JP124.7, JP124.9, JP125.1, JP125.3, JP125.5, JP125.7, JP125.9, R92.1, R98.2, R103.2, R104.2, U43.4, U43.6, U43.18, U45.20, U46.5, U47.1, U47.3, U48.5
5V8: C65.1, C66.1, C67.1, C72.A, JP135.3, JP135.4, JP136.3, JP136.4, JP137.3, JP137.4, JP138.3, JP138.4, JP139.2, JP140.1, JP140.3, JP140.5, JP140.7, JP140.9, JP141.1, JP141.3, JP141.5, JP141.7, JP141.9, R105.1, R111.2, R116.2, R117.2, U49.4, U49.6, U49.18, U51.20, U52.5, U53.1, U53.3, U54.5
FT232_RXI: R3.1, U5.5
FT232_RXI1: R16.1, U8.5
FT232_RXI2: R29.1, U14.5
FT232_RXI3: R42.1, U20.5
FT232_RXI4: R55.1, U26.5
FT232_RXI5: R68.1, U32.5
FT232_RXI6: R81.1, U38.5
FT232_RXI7: R94.1, U44.5
FT232_RXI8: R107.1, U50.5
FT232_TXO: R2.1, U5.1
FT232_TXO1: R15.1, U8.1
FT232_TXO2: R28.1, U14.1
FT232_TXO3: R41.1, U20.1
FT232_TXO4: R54.1, U26.1
FT232_TXO5: R67.1, U32.1
FT232_TXO6: R80.1, U38.1
FT232_TXO7: R93.1, U44.1
FT232_TXO8: R106.1, U50.1
FTDI_DTR: R13.1, U5.2, U6.1
FTDI_DTR1: R26.1, U8.2, U12.1
FTDI_DTR2: R39.1, U14.2, U18.1
FTDI_DTR3: R52.1, U20.2, U24.1
FTDI_DTR4: R65.1, U26.2, U30.1
FTDI_DTR5: R78.1, U32.2, U36.1
FTDI_DTR6: R91.1, U38.2, U42.1
FTDI_DTR7: R104.1, U44.2, U48.1
FTDI_DTR8: R117.1, U50.2, U54.1
GND: C2.2, C3.2, C4.2, C5.2, C6.2, C8.C, C9.C, D4.C, D6.C, JP3.GND, JP3.P$4, JP4.GND, JP5.6, JP6.2, JP6.4, JP6.6, JP6.8, JP6.10, JP7.2, JP7.4, JP7.6, JP7.8, JP7.10, JP8.5, JP8.6, JP9.5, JP9.6, JP10.5, JP10.6, JP11.5, JP11.6, JP12.5, JP12.6, JP13.5, JP13.6, JP16.1, MOD1.10, Q1.1, S1.3, S1.6, S2.3, S4.1, S5.1, U1.3, U1.5, U1.21, U2.3, U2.4, U2.9, U2.10, U2.18, U3.2, U4.2, U5.7, U5.18, U5.21, U5.25, U5.26, U6.3, Y1.2
GND1: C1.2, C10.2, C11.2, C12.2, C13.2, C15.C, C16.C, D10.C, D12.C, JP17.GND, JP17.P$4, JP18.GND, JP21.5, JP21.6, JP22.5, JP22.6, JP23.5, JP23.6, JP24.5, JP24.6, JP25.5, JP25.6, JP26.5, JP26.6, JP27.6, JP28.2, JP28.4, JP28.6, JP28.8, JP28.10, JP29.2, JP29.4, JP29.6, JP29.8, JP29.10, JP32.1, MOD2.10, Q2.1, S6.3, S6.6, S7.3, S9.1, S10.1, U7.3, U7.5, U7.21, U8.7, U8.18, U8.21, U8.25, U8.26, U9.3, U9.4, U9.9, U9.10, U9.18, U10.2, U11.2, U12.3, Y2.2
GND2: C17.2, C18.2, C19.2, C20.2, C21.2, C23.C, C24.C, D16.C, D18.C, JP33.GND, JP33.P$4, JP34.GND, JP37.5, JP37.6, JP38.5, JP38.6, JP39.5, JP39.6, JP40.5, JP40.6, JP41.5, JP41.6, JP42.5, JP42.6, JP43.6, JP44.2, JP44.4, JP44.6, JP44.8, JP44.10, JP45.2, JP45.4, JP45.6, JP45.8, JP45.10, JP48.1, MOD3.10, Q3.1, S11.3, S11.6, S12.3, S14.1, S15.1, U13.3, U13.5, U13.21, U14.7, U14.18, U14.21, U14.25, U14.26, U15.3, U15.4, U15.9, U15.10, U15.18, U16.2, U17.2, U18.3, Y3.2
GND3: C25.2, C26.2, C27.2, C28.2, C29.2, C31.C, C32.C, D22.C, D24.C, JP49.GND, JP49.P$4, JP50.GND, JP53.5, JP53.6, JP54.5, JP54.6, JP55.5, JP55.6, JP56.5, JP56.6, JP57.5, JP57.6, JP58.5, JP58.6, JP59.6, JP60.2, JP60.4, JP60.6, JP60.8, JP60.10, JP61.2, JP61.4, JP61.6, JP61.8, JP61.10, JP64.1, MOD4.10, Q4.1, S16.3, S16.6, S17.3, S19.1, S20.1, U19.3, U19.5, U19.21, U20.7, U20.18, U20.21, U20.25, U20.26, U21.3, U21.4, U21.9, U21.10, U21.18, U22.2, U23.2, U24.3, Y4.2
GND4: C33.2, C34.2, C35.2, C36.2, C37.2, C39.C, C40.C, D28.C, D30.C, JP65.GND, JP65.P$4, JP66.GND, JP69.5, JP69.6, JP70.5, JP70.6, JP71.5, JP71.6, JP72.5, JP72.6, JP73.5, JP73.6, JP74.5, JP74.6, JP75.6, JP76.2, JP76.4, JP76.6, JP76.8, JP76.10, JP77.2, JP77.4, JP77.6, JP77.8, JP77.10, JP80.1, MOD5.10, Q5.1, S21.3, S21.6, S22.3, S24.1, S25.1, U25.3, U25.5, U25.21, U26.7, U26.18, U26.21, U26.25, U26.26, U27.3, U27.4, U27.9, U27.10, U27.18, U28.2, U29.2, U30.3, Y5.2
GND5: C41.2, C42.2, C43.2, C44.2, C45.2, C47.C, C48.C, D34.C, D36.C, JP81.GND, JP81.P$4, JP82.GND, JP85.5, JP85.6, JP86.5, JP86.6, JP87.5, JP87.6, JP88.5, JP88.6, JP89.5, JP89.6, JP90.5, JP90.6, JP91.6, JP92.2, JP92.4, JP92.6, JP92.8, JP92.10, JP93.2, JP93.4, JP93.6, JP93.8, JP93.10, JP96.1, MOD6.10, Q6.1, S26.3, S26.6, S27.3, S29.1, S30.1, U31.3, U31.5, U31.21, U32.7, U32.18, U32.21, U32.25, U32.26, U33.3, U33.4, U33.9, U33.10, U33.18, U34.2, U35.2, U36.3, Y6.2
GND6: C49.2, C50.2, C51.2, C52.2, C53.2, C55.C, C56.C, D40.C, D42.C, JP97.GND, JP97.P$4, JP98.GND, JP101.5, JP101.6, JP102.5, JP102.6, JP103.5, JP103.6, JP104.5, JP104.6, JP105.5, JP105.6, JP106.5, JP106.6, JP107.6, JP108.2, JP108.4, JP108.6, JP108.8, JP108.10, JP109.2, JP109.4, JP109.6, JP109.8, JP109.10, JP112.1, MOD7.10, Q7.1, S31.3, S31.6, S32.3, S34.1, S35.1, U37.3, U37.5, U37.21, U38.7, U38.18, U38.21, U38.25, U38.26, U39.3, U39.4, U39.9, U39.10, U39.18, U40.2, U41.2, U42.3, Y7.2
GND7: C57.2, C58.2, C59.2, C60.2, C61.2, C63.C, C64.C, D46.C, D48.C, JP113.GND, JP113.P$4, JP114.GND, JP117.5, JP117.6, JP118.5, JP118.6, JP119.5, JP119.6, JP120.5, JP120.6, JP121.5, JP121.6, JP122.5, JP122.6, JP123.6, JP124.2, JP124.4, JP124.6, JP124.8, JP124.10, JP125.2, JP125.4, JP125.6, JP125.8, JP125.10, JP128.1, MOD8.10, Q8.1, S36.3, S36.6, S37.3, S39.1, S40.1, U43.3, U43.5, U43.21, U44.7, U44.18, U44.21, U44.25, U44.26, U45.3, U45.4, U45.9, U45.10, U45.18, U46.2, U47.2, U48.3, Y8.2
GND8: C65.2, C66.2, C67.2, C68.2, C69.2, C71.C, C72.C, D52.C, D54.C, JP129.GND, JP129.P$4, JP130.GND, JP133.5, JP133.6, JP134.5, JP134.6, JP135.5, JP135.6, JP136.5, JP136.6, JP137.5, JP137.6, JP138.5, JP138.6, JP139.6, JP140.2, JP140.4, JP140.6, JP140.8, JP140.10, JP141.2, JP141.4, JP141.6, JP141.8, JP141.10, JP144.1, MOD9.10, Q9.1, S41.3, S41.6, S42.3, S44.1, S45.1, U49.3, U49.5, U49.21, U50.7, U50.18, U50.21, U50.25, U50.26, U51.3, U51.4, U51.9, U51.10, U51.18, U52.2, U53.2, U54.3, Y9.2
L01: JP1.1, JP1.3, JP15.2, U2.1, U2.2
L02: JP1.2, JP15.1, U2.5, U2.6
L03: JP19.1, JP19.3, JP31.2, U9.1, U9.2
L04: JP19.2, JP31.1, U9.5, U9.6
L05: JP35.1, JP35.3, JP47.2, U15.1, U15.2
L06: JP35.2, JP47.1, U15.5, U15.6
L07: JP51.1, JP51.3, JP63.2, U21.1, U21.2
L08: JP51.2, JP63.1, U21.5, U21.6
L09: JP67.1, JP67.3, JP79.2, U27.1, U27.2
L10: JP67.2, JP79.1, U27.5, U27.6
L11: JP83.1, JP83.3, JP95.2, U33.1, U33.2
L12: JP83.2, JP95.1, U33.5, U33.6
L13: JP99.1, JP99.3, JP111.2, U39.1, U39.2
L14: JP99.2, JP111.1, U39.5, U39.6
L15: JP115.1, JP115.3, JP127.2, U45.1, U45.2
L16: JP115.2, JP127.1, U45.5, U45.6
L17: JP131.1, JP131.3, JP143.2, U51.1, U51.2
L18: JP131.2, JP143.1, U51.5, U51.6
L_CTRL_1: U1.32, U2.21
L_CTRL_2: U1.2, U2.22
L_CTRL_3: U7.2, U9.22
L_CTRL_4: U7.32, U9.21
L_CTRL_5: U13.2, U15.22
L_CTRL_6: U13.32, U15.21
L_CTRL_7: U19.2, U21.22
L_CTRL_8: U19.32, U21.21
L_CTRL_9: U25.2, U27.22
L_CTRL_10: U25.32, U27.21
L_CTRL_11: U31.2, U33.22
L_CTRL_12: U31.32, U33.21
L_CTRL_13: U37.2, U39.22
L_CTRL_14: U37.32, U39.21
L_CTRL_15: U43.2, U45.22
L_CTRL_16: U43.32, U45.21
L_CTRL_17: U49.2, U51.22
L_CTRL_18: U49.32, U51.21
MISO: JP5.1, S5.3, U1.16
MISO1: JP27.1, S10.3, U7.16
MISO2: JP43.1, S15.3, U13.16
MISO3: JP59.1, S20.3, U19.16
MISO4: JP75.1, S25.3, U25.16
MISO5: JP91.1, S30.3, U31.16
MISO6: JP107.1, S35.3, U37.16
MISO7: JP123.1, S40.3, U43.16
MISO8: JP139.1, S45.3, U49.16
MOTOR_ENABLE: S1.5, S2.2, U2.19
MOTOR_ENABLE1: S6.5, S7.2, U9.19
MOTOR_ENABLE2: S11.5, S12.2, U15.19
MOTOR_ENABLE3: S16.5, S17.2, U21.19
MOTOR_ENABLE4: S21.5, S22.2, U27.19
MOTOR_ENABLE5: S26.5, S27.2, U33.19
MOTOR_ENABLE6: S31.5, S32.2, U39.19
MOTOR_ENABLE7: S36.5, S37.2, U45.19
MOTOR_ENABLE8: S41.5, S42.2, U51.19
unnamed: R4.2, S3.2
unnamed: Q1.4, Q1.7, Q1.8, R11.1
unnamed: D5.C, R6.1
unnamed: D3.C, R5.1
unnamed: C7.2, U6.4
unnamed: JP4.MTN1, JP4.MTN2, JP4.MTN3, JP4.MTN4
unnamed: D4.A, R7.1
unnamed: D6.A, R8.1
unnamed: F1.2, Q1.5, Q1.6
unnamed: JP18.D-, U8.16
unnamed: JP18.D+, U8.15
unnamed: U7.8, Y2.3
unnamed: U7.7, Y2.1
unnamed: D10.A, R19.1
unnamed: D12.A, R20.1
unnamed: R21.1, S7.1
unnamed: C14.2, U12.4
unnamed: R9.1, S2.1
unnamed: R23.2, S8.2
unnamed: JP18.MTN1, JP18.MTN2, JP18.MTN3, JP18.MTN4
unnamed: Q2.4, Q2.7, Q2.8, R24.1
unnamed: D11.C, R18.1
unnamed: U1.8, Y1.3
unnamed: U1.7, Y1.1
unnamed: D9.C, R17.1
unnamed: JP4.D-, U5.16
unnamed: JP4.D+, U5.15
unnamed: F2.2, Q2.5, Q2.6
unnamed: JP34.D-, U14.16
unnamed: JP34.D+, U14.15
unnamed: U13.8, Y3.3
unnamed: U13.7, Y3.1
unnamed: D16.A, R32.1
unnamed: D18.A, R33.1
unnamed: R34.1, S12.1
unnamed: C22.2, U18.4
unnamed: R36.2, S13.2
unnamed: JP34.MTN1, JP34.MTN2, JP34.MTN3, JP34.MTN4
unnamed: Q3.4, Q3.7, Q3.8, R37.1
unnamed: D17.C, R31.1
unnamed: D15.C, R30.1
unnamed: F3.2, Q3.5, Q3.6
unnamed: JP50.D-, U20.16
unnamed: JP50.D+, U20.15
unnamed: U19.8, Y4.3
unnamed: U19.7, Y4.1
unnamed: D22.A, R45.1
unnamed: D24.A, R46.1
unnamed: R47.1, S17.1
unnamed: C30.2, U24.4
unnamed: R49.2, S18.2
unnamed: JP50.MTN1, JP50.MTN2, JP50.MTN3, JP50.MTN4
unnamed: Q4.4, Q4.7, Q4.8, R50.1
unnamed: D23.C, R44.1
unnamed: D21.C, R43.1
unnamed: F4.2, Q4.5, Q4.6
unnamed: JP66.D-, U26.16
unnamed: JP66.D+, U26.15
unnamed: U25.8, Y5.3
unnamed: U25.7, Y5.1
unnamed: D28.A, R58.1
unnamed: D30.A, R59.1
unnamed: R60.1, S22.1
unnamed: C38.2, U30.4
unnamed: R62.2, S23.2
unnamed: JP66.MTN1, JP66.MTN2, JP66.MTN3, JP66.MTN4
unnamed: Q5.4, Q5.7, Q5.8, R63.1
unnamed: D29.C, R57.1
unnamed: D27.C, R56.1
unnamed: F5.2, Q5.5, Q5.6
unnamed: JP82.D-, U32.16
unnamed: JP82.D+, U32.15
unnamed: U31.8, Y6.3
unnamed: U31.7, Y6.1
unnamed: D34.A, R71.1
unnamed: D36.A, R72.1
unnamed: R73.1, S27.1
unnamed: C46.2, U36.4
unnamed: R75.2, S28.2
unnamed: JP82.MTN1, JP82.MTN2, JP82.MTN3, JP82.MTN4
unnamed: Q6.4, Q6.7, Q6.8, R76.1
unnamed: D35.C, R70.1
unnamed: D33.C, R69.1
unnamed: F6.2, Q6.5, Q6.6
unnamed: JP98.D-, U38.16
unnamed: JP98.D+, U38.15
unnamed: U37.8, Y7.3
unnamed: U37.7, Y7.1
unnamed: D40.A, R84.1
unnamed: D42.A, R85.1
unnamed: R86.1, S32.1
unnamed: C54.2, U42.4
unnamed: R88.2, S33.2
unnamed: JP98.MTN1, JP98.MTN2, JP98.MTN3, JP98.MTN4
unnamed: Q7.4, Q7.7, Q7.8, R89.1
unnamed: D41.C, R83.1
unnamed: D39.C, R82.1
unnamed: F7.2, Q7.5, Q7.6
unnamed: JP114.D-, U44.16
unnamed: JP114.D+, U44.15
unnamed: U43.8, Y8.3
unnamed: U43.7, Y8.1
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

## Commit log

2012-10-30 Initial commit.
    [RedBot.brd, RedBot.sch]
2012-11-09 v01 files as sent to protos
    [RedBot.brd, RedBot.sch]
2012-12-10 v02 hardware file commit
    Initial protos are messed up- no internal copper layers.
    Took this opportunity to add a couple of new features:
    - .1" headers for input voltage and motor connections
    - PMOS switch to disconnect servos when powered down
    - fixed barrel jack so the right pin is to ground
    [RedBot.brd, RedBot.sch]
2012-12-10 Last commit incomplete; this adds header for PS
    [RedBot.brd, RedBot.sch]
2012-12-18 Changes from v01 Changed top plane to ground Fixed issue with barrel jack connection Add .1" header for power input by barrel jack Add PMOSFET power switch for servo motors
    [RedBot.brd]
2013-01-10 Fix a couple of problems: - TEST pin on FTDI chip needs to be grounded. - FTDI chip not properly bypassed.
    [RedBot.brd, RedBot.sch]
2013-01-21 Added an AND gate to the reset lines, to improve the multiplexing capabilities of the Xbee/FTDI during bootloads.
    [RedBot.brd, RedBot.sch]
2013-02-12 V03 prototypes - Added an AND gate instead of two diodes for reset control - Changed packages on the 5x2 headers along the board edges to be no silk - Moved motor header text to avoid tmask interfere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
    [RedBot.brd, RedBot.sch]
2013-05-15 Change board/schematic to v10 - Tweaks to board labels - Change as many 0.015" vias to 0.020" as possible. - Address a few minor clearance issues.
    [RedBot.brd, RedBot.sch]
2013-05-15 Moved User LED to pin 13
    [RedBot.brd, RedBot.sch]
2013-05-27 Production readied
    add fiducials & create panel
    [11414-RedBot-Panel-v10.brd, RedBot.sch]
2013-07-02 Fix polarity issue on FT232 LEDs
    [RedBot.brd, RedBot.sch]
2013-07-03 Panelized v11 board
    [RedBot-Panel-v11.brd]
2013-07-15 add Arduino files/library
2013-07-24 Update parts to 0603
    [RedBot.brd, RedBot.sch]
2013-07-25 Created v12 panel
    [RedBot-Panel-v12.brd]
2013-08-08 Hardware to v13 - Fix gating of battery voltage to servos - Add a user input button to pin 12 - label user led as D13 LED for clarity
    [RedBot.brd, RedBot.sch]
2013-09-03 Fixing Arduino library structure
2013-10-03 Added support for encoder and whisker bumper; changing schematic and layout to fix some issues and pretty it up a bit. Hardware changes not done!
    [RedBot.brd, RedBot.sch]
2013-10-07 Changes to library, changes to board. Will need to do some branching magic to separate the two. This will become the sw dev branch.
    [RedBot.brd, RedBot.sch]
2013-10-07 Update boards to v13. - Flip MOSFET to gate power to Servo headers - Add button to pin 12 - change silk on LED to D13 LED - add some silk to the back
    [RedBot.brd, RedBot.sch]
2013-10-07 Rollback design to current master
    [RedBot.brd, RedBot.sch]
2013-10-08 Added RedBot logo
    [RedBot.brd, RedBot.sch]
2013-10-10 Encoder and bumper fixes
2013-11-26 Added PTC to V_GATED
    [RedBot.brd, RedBot.sch]
2013-11-26 created panel
    [RedBot-Panel-v12.brd, RedBot-Panel-v14.brd]
2014-01-04 Adds documentation to the RedBot Arduino library.
    Only documentation to the classes public members and methods was
    added as the implementation files are sufficiently documented for
    people who really want to dig.
2014-02-06 Add missing files to Arduino library
2014-03-04 Fix infinite loop if no I2C dev present
2014-03-04 Implement timeout for I2C transactions
2014-03-04 Add timeout to all I2C transactions
2014-03-04 FINALLY fixed I2C no-slave issue - Added timeout to each step of the I2C transaction - Learned my lesson about one-line conditional statements
2014-10-10 PlatformIO Library Manager manifest file
    * This library in Web: http://platformio.ikravets.com/#!/lib/show/Arduino-RedBot
    * Specification: [PlatformIO Library Manager](http://docs.platformio.ikravets.com/en/latest/librarymanager/index.html)
    * Integration: [IDE Integration](http://docs.platformio.ikravets.com/en/latest/ide.html)
    `library.json` is a library manifest file which can be used with different tools/managers to organise embedded libraries. Currently, only [PlatformIO](http://platformio.ikravets.com) uses it. How doe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
    ```bash
    $ platformio lib search “+arduino redbot"
    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
2014-12-16 Updated example code and library
    - Updated example / experiment code.
    - Re-named RedBotMotor to RedBotMotors.
    - Added a .coast() method as more appropriately describing
    functionality.
    - Added a .leftMotor() and a .rightMotor() method that allows
    independent control of the right and left motor. Positive values are CW,
    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
2015-12-16 created larger v14a panel
    [RedBot-Panel-v14.brd, RedBot_Panel_v14a.brd]
2016-03-03 Squashed 'Libraries/Arduino/' content from commit 88cbdfa
    git-subtree-dir: Libraries/Arduino
    git-subtree-split: 88cbdfa4552ccab708695102eaf8b9ba84870a82
2016-03-03 Squashed 'Libraries/Arduino/' changes from 88cbdfa..220f016
    220f016 Adding example 4_2, updating 4_1, 6_1, 6_2, 7_1 meta data
    ee186a0 Updating example 7_3
    git-subtree-split: 220f01668567be4ad0f3be12d2eeb6cd0d746865
    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
2016-03-15 Squashed 'Libraries/Arduino/' changes from 220f016..cc6a482
    cc6a482 Adding .json file for PlatformIO
    git-subtree-split: cc6a482827ecb4866a96b3ec569d3d5d16813a59
    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

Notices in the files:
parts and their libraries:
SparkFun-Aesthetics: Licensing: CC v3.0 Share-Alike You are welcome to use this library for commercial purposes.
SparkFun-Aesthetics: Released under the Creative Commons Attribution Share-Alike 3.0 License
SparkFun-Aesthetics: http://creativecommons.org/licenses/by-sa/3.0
